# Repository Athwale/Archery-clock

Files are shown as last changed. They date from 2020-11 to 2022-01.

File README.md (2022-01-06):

# REV1 boards have not been built and tested yet.
If you intend to build it, please wait.

# Archery-clock
This repository contains electronic designs and software for a custom built sport archery clock used by www.patriotbrno.cz

## V2
V2 is the current design which uses a Raspberry pi 3 and is controlled over wi-fi using a smartphone or a computer.  
It is built to be more modular and easier to build or repair.

## PCBs
The DXF and Gerber files are exported from copper side and must be mirror flipped by the manufacturer to produce correct boards, KiCad does not have this functionality built in. Drill files are included, but should be checked and adjusted according to your needs.  
Check the position of pin 1 on the microcontroller (square pad in the design) for correct stencil placement.

## Control software  
The clock has a web based user interface that you can use from a wif-fi capable phone or computer.  
This software is being developed here:  
https://github.com/zmej/arclock

### Viewing the designs
Electronic designs were made in KiCad.

### Disclaimer
These designs were not professionally produced nor rigorously tested by any institution. You are building this device on your own and you accept all responsibility for it's function and operation.

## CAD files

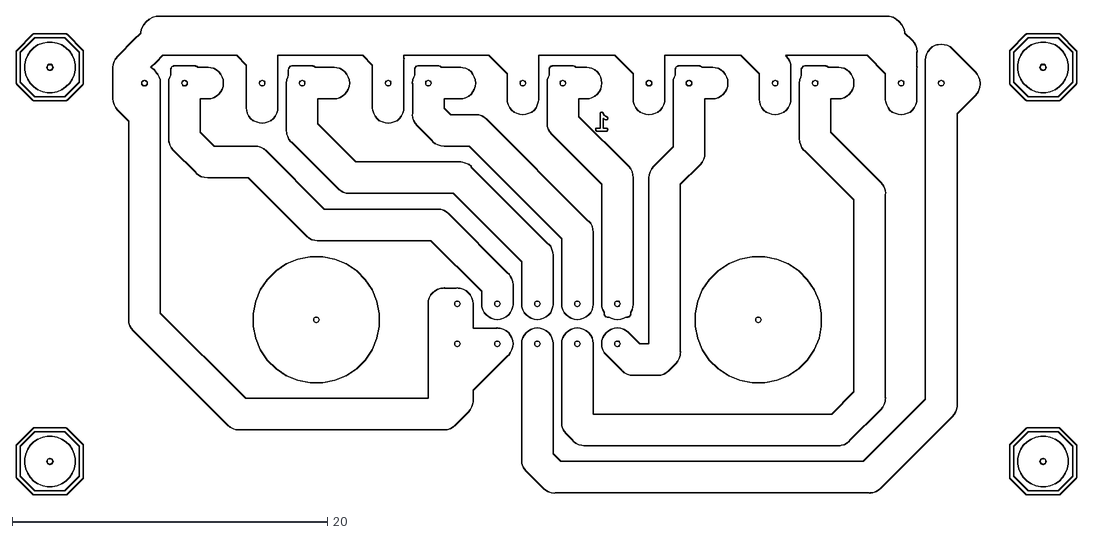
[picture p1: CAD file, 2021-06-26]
V2-rev1/Hardware/breakout/DXF/breakout-B_Cu.dxf
67.3 x 30.4

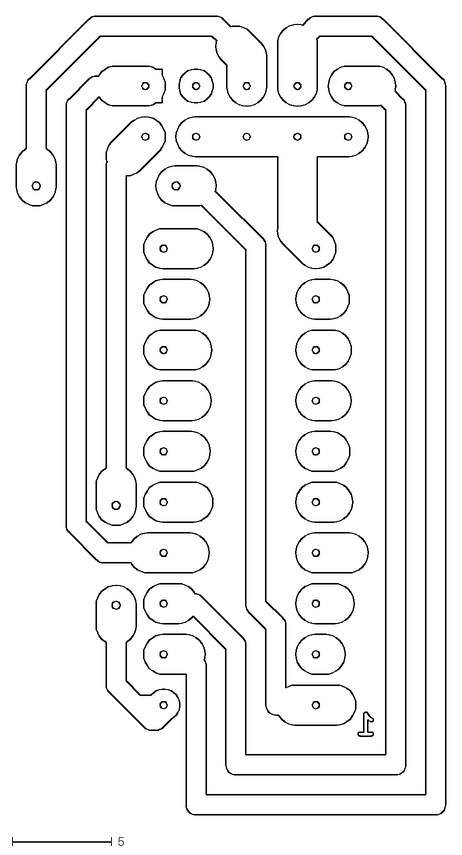
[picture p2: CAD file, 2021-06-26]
V2-rev1/Hardware/burner/DXF/burner-B_Cu.dxf
21.5 x 40.0

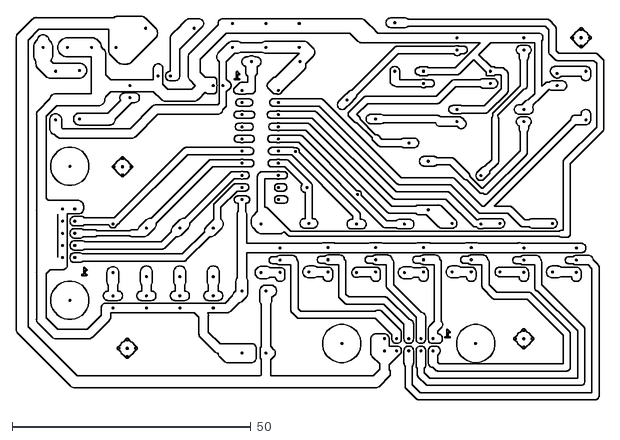
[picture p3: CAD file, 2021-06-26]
V2-rev1/Hardware/controller/DXF/controller-B_Cu.dxf
123.0 x 80.3

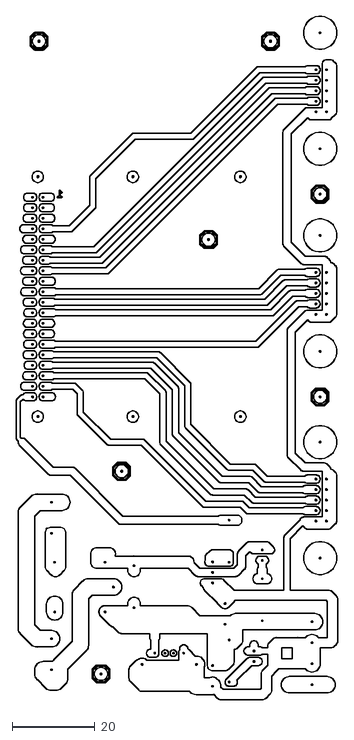
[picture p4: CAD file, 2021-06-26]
V2-rev1/Hardware/splitter/DXF/splitter-B_Cu.dxf
77.8 x 165.3

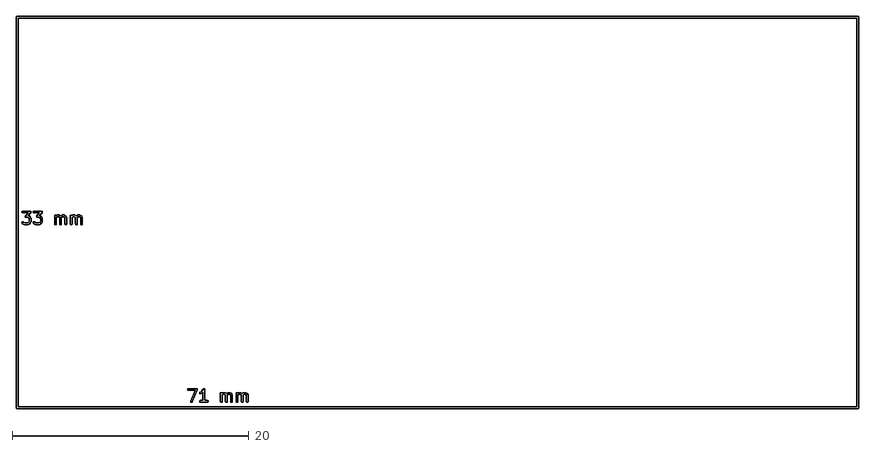
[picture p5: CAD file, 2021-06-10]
V2-rev1/Hardware/breakout/DXF/breakout-Eco2_User.dxf
71.1 x 33.2

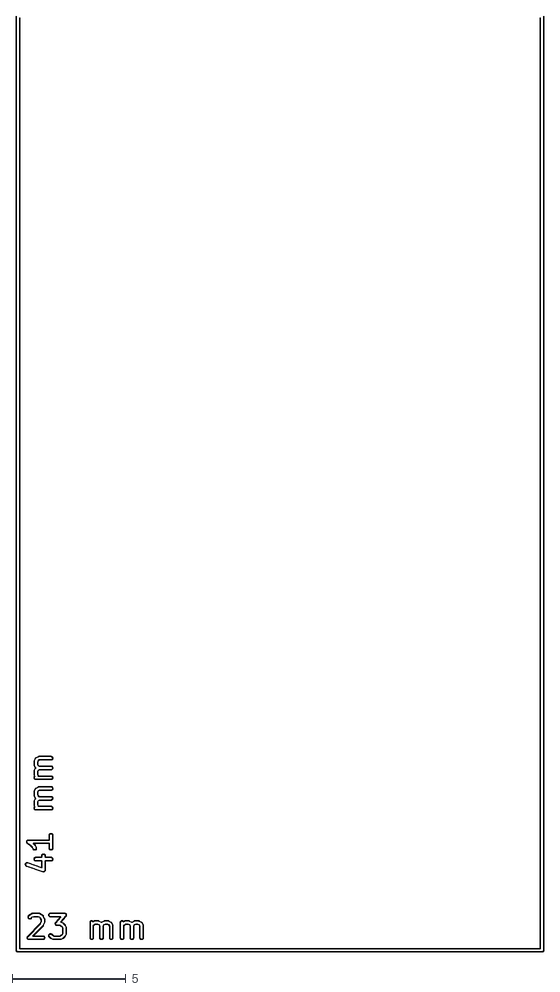
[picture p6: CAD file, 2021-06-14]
V2-rev1/Hardware/burner/DXF/burner-Eco2_User.dxf
23.1 x 41.1

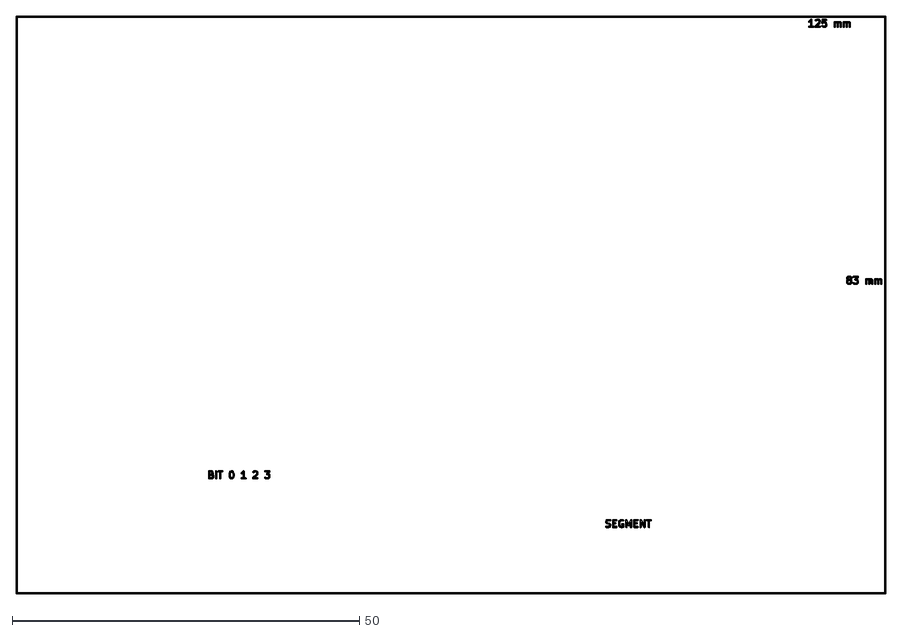
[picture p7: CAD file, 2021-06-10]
V2-rev1/Hardware/controller/DXF/controller-Eco2_User.dxf
125.2 x 83.2

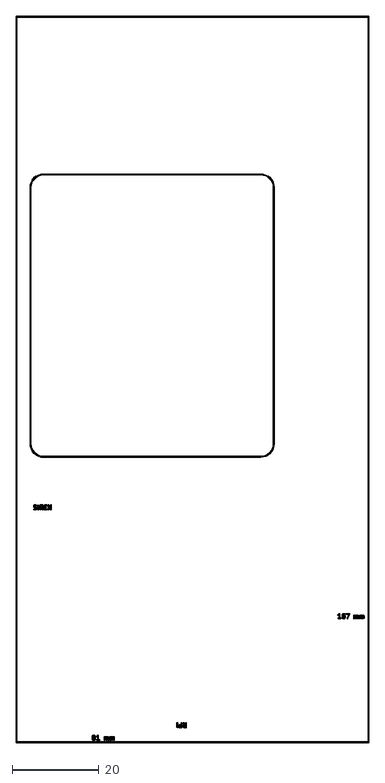
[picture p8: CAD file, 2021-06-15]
V2-rev1/Hardware/splitter/DXF/splitter-Eco2_User.dxf
81.2 x 167.2

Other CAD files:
V2-rev1/Hardware/breakout/DXF/breakout-B_Mask.dxf
V2-rev1/Hardware/burner/DXF/burner-B_Mask.dxf
V2-rev1/Hardware/controller/DXF/controller-B_Mask.dxf
V2-rev1/Hardware/splitter/DXF/splitter-B_Mask.dxf

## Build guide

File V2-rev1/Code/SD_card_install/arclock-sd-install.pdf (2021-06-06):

# ARCLOCK Image

Dokumentace je napsaná pro OS Linux. U nás nepoužíváme Windows, ale ve Windows budou určitě existovat ekvivalentní nástroje.

Stav. V hodinách byla SD karta 16GB a měli jsme rezervní kartu jen 8GB. Potřebovali jsme vyzkoušet, že stažený image bude po restore opět fungovat.
Když jsem stahoval image z SDD16GB pomoci dd a ten jsem opět pomocí dd nahrál na SDD8GB, tak hodiny nenaběhly.

Proto jsme použili utilitu image-backup. Ta neni v Raspbianu předinstalovaná a bylo potřeba ji doinstalovat.

image-backup jsme nainstalovali do adresáře /home/pi/utils

# Příprava záložního média

Image SDD karty je potřeba umístit na záložní médium, u mě to byl USB flash disk. Image vyžaduje zhruba 5GB, ale přidali jsme zhruba 2GB volného místa, aby byla rezerva na logy a pod.
Na USB flash disku jsem vytvořil dostatečně velký partition se souborovým systémem Ext4. Image má skoro 7GB a souborový systém musí zvládnout práci s tak velkým souborem.

# Vytvoření image

Do USB portu RPi zasunout připravené záložní médium.

Spustit image-backup. V našem případě by to vypadalo:

$ sudo ~/utils/image-backup

image-backup pracuje interaktivne a postupně se zeptá na následujćí otázky:
- Název souboru s image. Musí obsahovat cestu na záložní médium, a to i v případě, že na záložním médiu je aktuální pracovní adresář. V mém přṕadě to bylo: /media/pi/samsung32g/rpi-arclock.img .
- Kolik místa má alokovat pro root file systém. Zadal jsem 7168.
- Kolik místa má přidat pro pozdější inkrementální backup. Zadal jsem 0
- Nakonec je potvrzení, že se má image vytvorit - y .

Zkomprimovat soubor:
$ gzip -k /media/pi/samsung32g/rpi-arclock.img

Vznikne soubor /media/pi/samsung32g/rpi-arclock.img.gz

Diky přepínači -k zůstane zachován i původní soubor.

# Instalace SD karty z image

Do svého notebooku jsem zasunul záložní médium do USB konektoru a SD kartu do SD slotu.

Rozbalit image soubor z archivu gz.

Zatím jsem nevyzkoušel instalovat SD kartu příkazem dd, pracoval jsem s GUI utilitou disks.
- Vybrat v levém panelu SD kartu.
- V nástrojové liště kliknou na druhé tlačítko zprava. To se třemi linkami.
- V menu vybrat Restore disk image ...

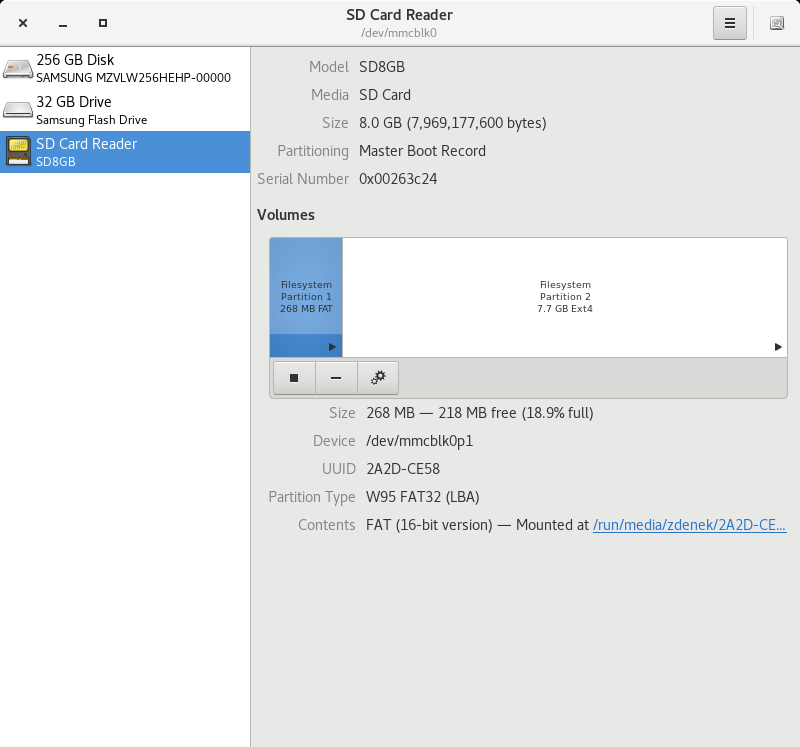
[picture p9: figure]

- Kliknout na tlačítko vedle nápisu Image to Restore a vybrat soubor.

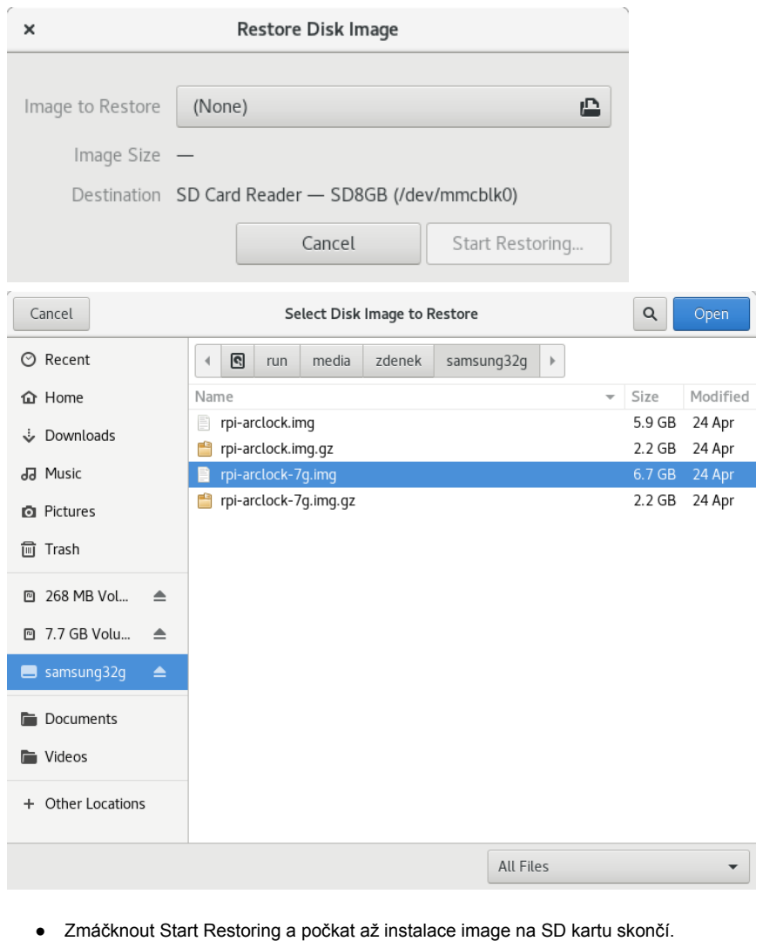
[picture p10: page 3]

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
ž in

s

t

ala

c

e im

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
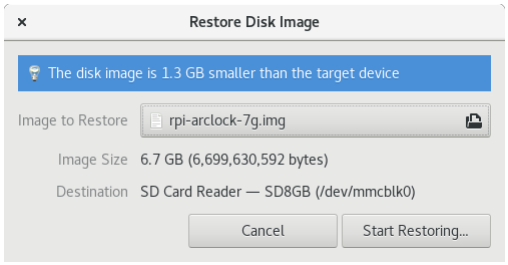
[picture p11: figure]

# Instalace SD karty do RPi

Zasunout SD kartu do slotu v RPi.

Zapnout hodiny.

Na RPI by měla celou dobu bootu blikat i zelená kontrolka. Pokud nebliká, je něco špatně.

Boot poměrně dlouho trvá, je potřeba vydržet.

Na konci bootu by se měly postupně na LEDkách kontrolérů, a je-li připojen displej, tak i na něm, rozsvítit a zhasnout číslice 8 a nakonec by na displeji měly svítit dvě pomlčky na místě jednotek a desítek.

Zapnout nějaké zařízení s Wifi, notebook, tablet, mobil.

V seznamu dostupných Wifi sítí by se měla objevit síť ArcheryClock

Připojit se k síti ArcheryClock. Heslo je whiteblinkingdot

Na zařízení spustit internetový prohlížeč. Testoval jsem s prohlížeči Firefox, Chrome. Zkusil jsem i se Safari, ale Sfari mělo problém, že vždy po dokončení odpočtu zapomělo nastavení a bylo potřeba znovu v UI nastavit řadu a délku odpočtu.

Do prohlížeče zadat adresu: 192.168.4.1:4000

Objeví se

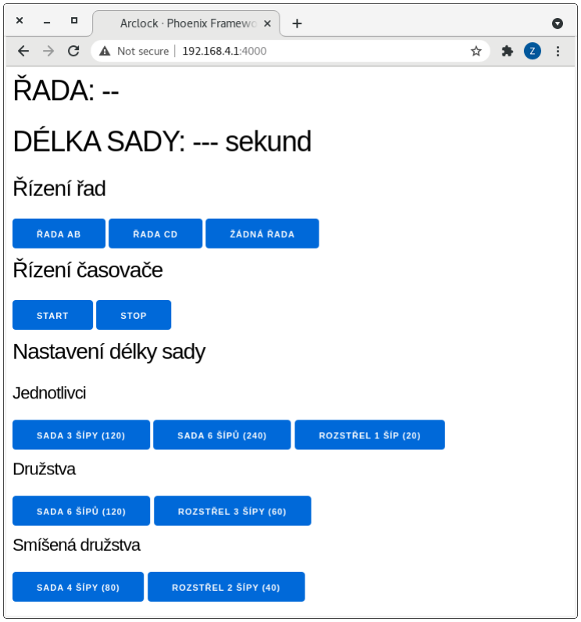
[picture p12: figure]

Zacházení s UI už nepotřebuje další komentář ;-) .

Hodiny nepotřebují žádnou speciální akci pro shutdown. Stačí vypnout přívod 230V.

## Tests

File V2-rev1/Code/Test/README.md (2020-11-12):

Microcontroller: AVR, EEPROM: 128B, SRAM: 128B, flash: 2kB, THT ATTINY2313-20PU DIL20  
Programmer: USBASP - USB 2.0 ISP programmer  
Burner SW: AVRDUDE  
OS: Fedora  
    
## Install:
```
sudo yum -y install avrdude avr-gcc avr-libc
```

### Simple LED test:
This compiles and creates a hex file for a small LED blinking test program which blinks all LEDs connected to port B at 500ms intervals using the default internal 1MHz rc oscillator.
```
avr-gcc -Wall -g -Os -mmcu=attiny2313 -o ledblink_test.bin ledblink_test.c  
avr-objcopy -j .text -j .data -O ihex ledblink_test.bin ledblink_test.hex  
```
  
#### Flash hex into the microcontroller:
```
avrdude -c usbasp -p attiny2313 -U flash:w:ledblink_test.hex
```

### Decoder IO test:
This test sends all possible displayable characters on port B using another attiny2313 using the internal 1MHz rc oscillator.
```
avr-gcc -Wall -g -Os -mmcu=attiny2313 -o io_test.bin io_test.c  
avr-objcopy -j .text -j .data -O ihex io_test.bin io_test.hex  
```
  
#### Flash hex into the microcontroller:
```
avrdude -c usbasp -p attiny2313 -U flash:w:io_test.hex
```

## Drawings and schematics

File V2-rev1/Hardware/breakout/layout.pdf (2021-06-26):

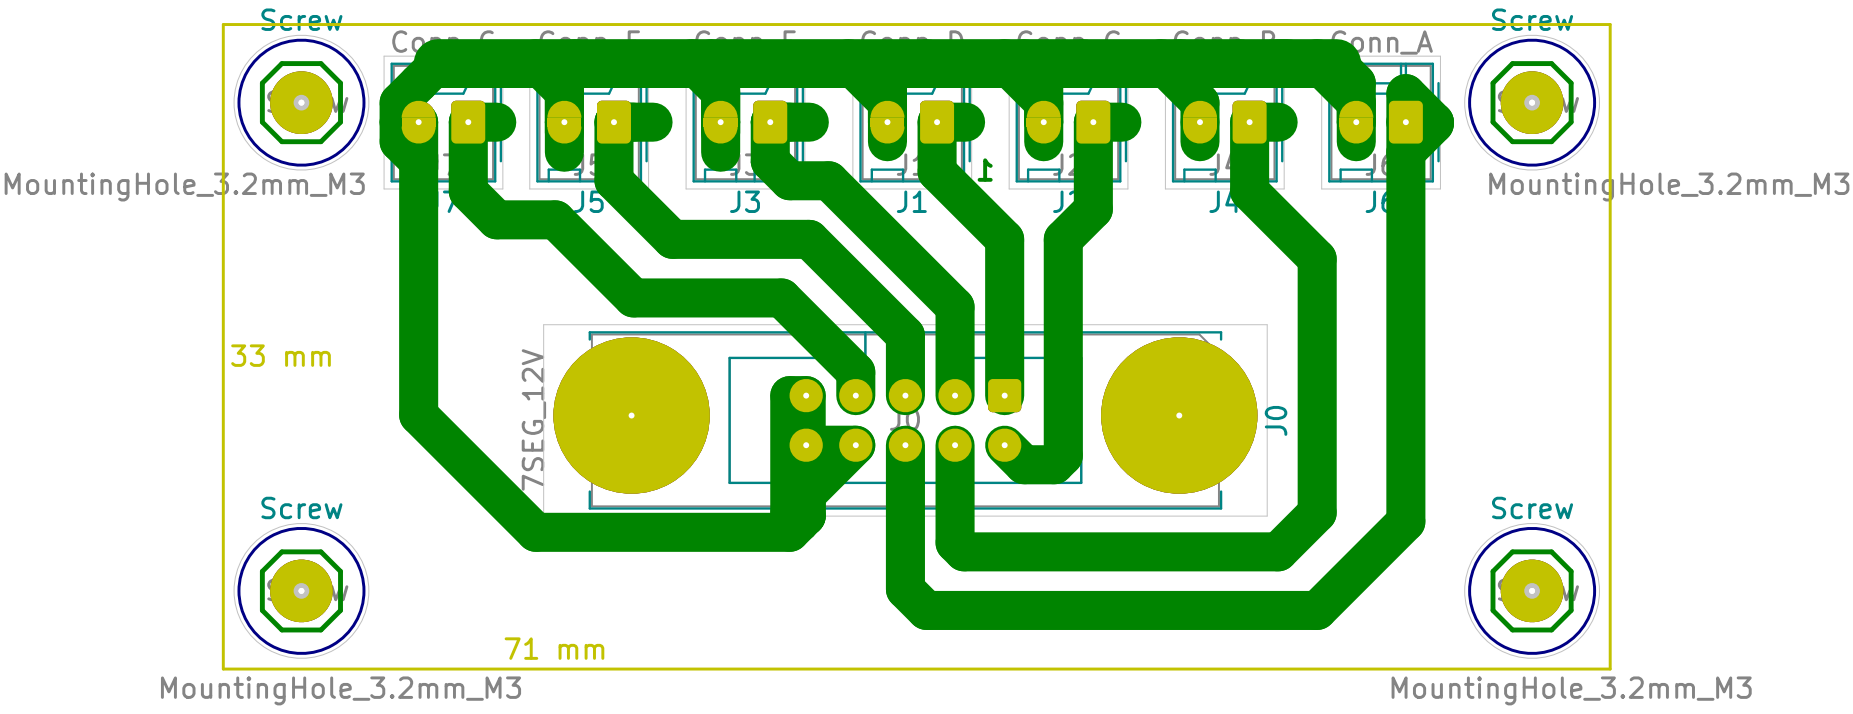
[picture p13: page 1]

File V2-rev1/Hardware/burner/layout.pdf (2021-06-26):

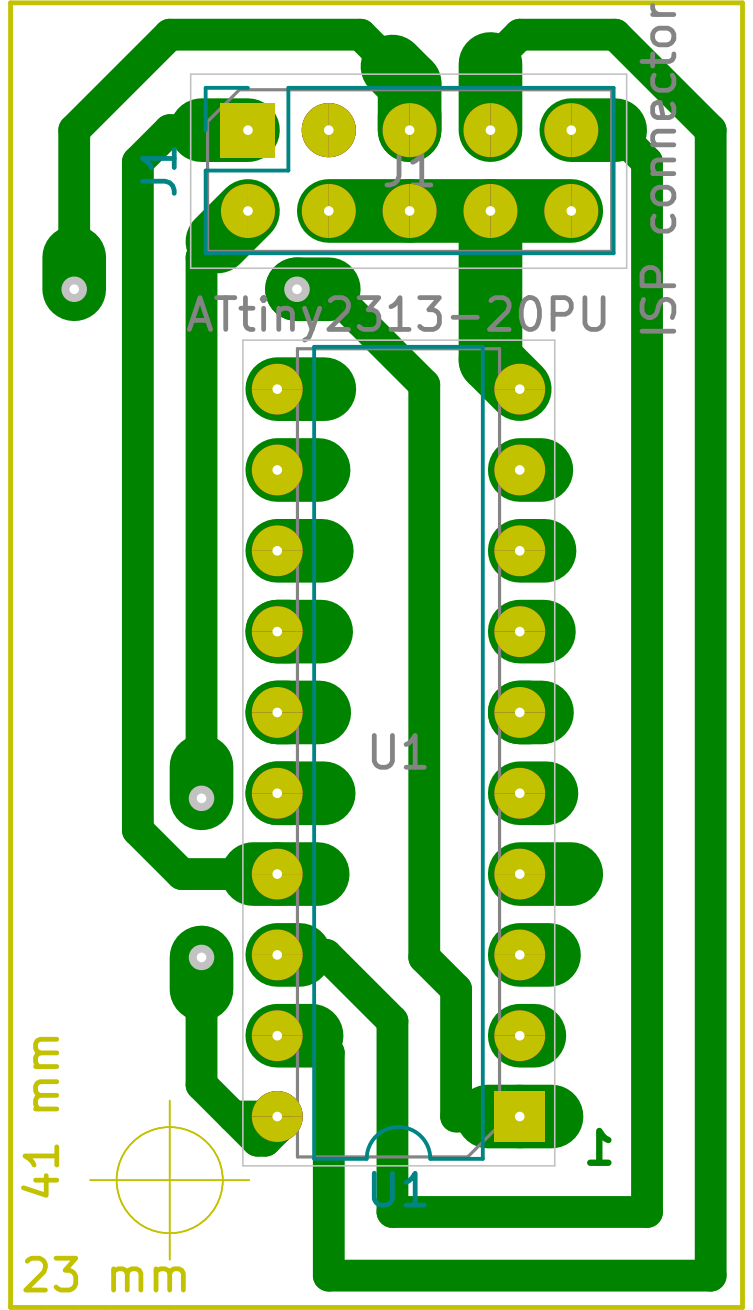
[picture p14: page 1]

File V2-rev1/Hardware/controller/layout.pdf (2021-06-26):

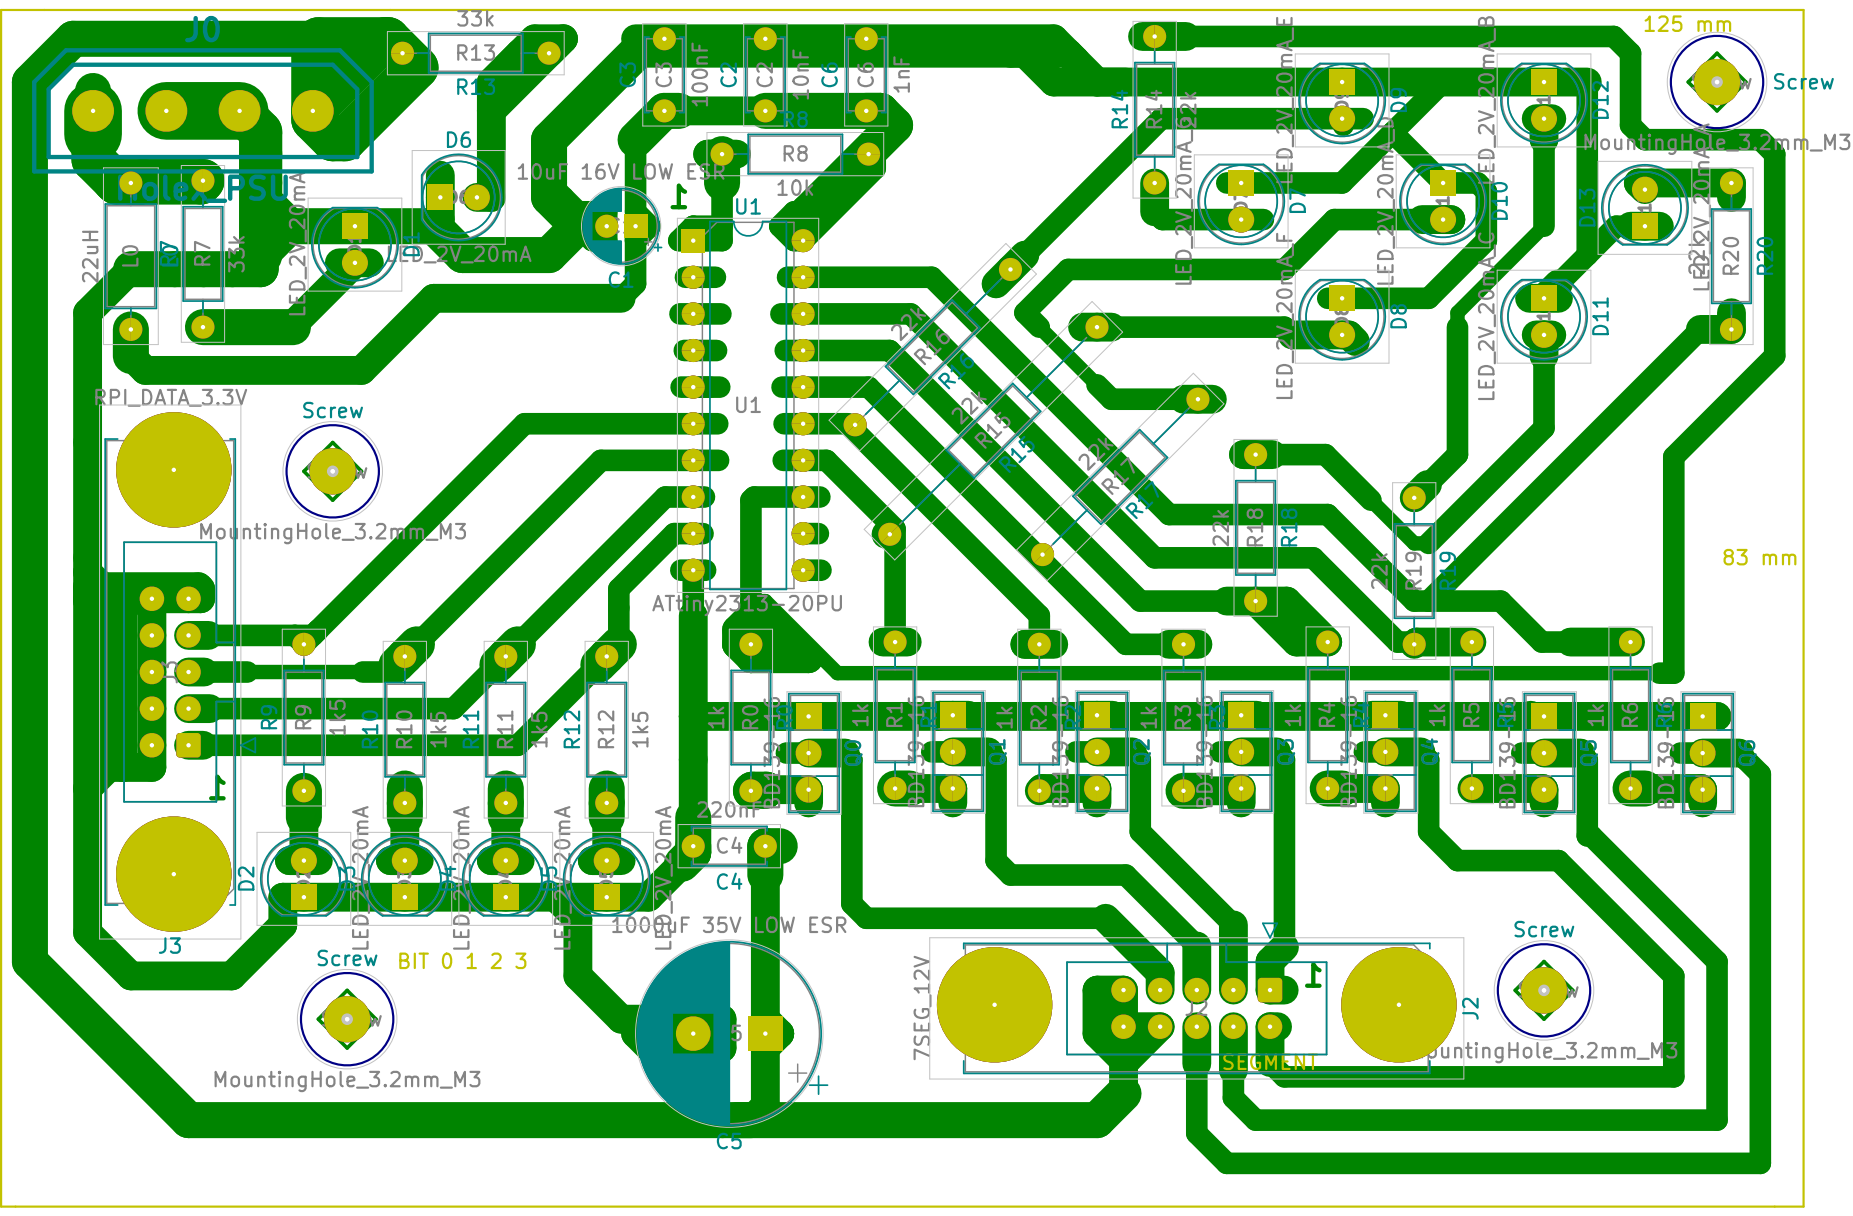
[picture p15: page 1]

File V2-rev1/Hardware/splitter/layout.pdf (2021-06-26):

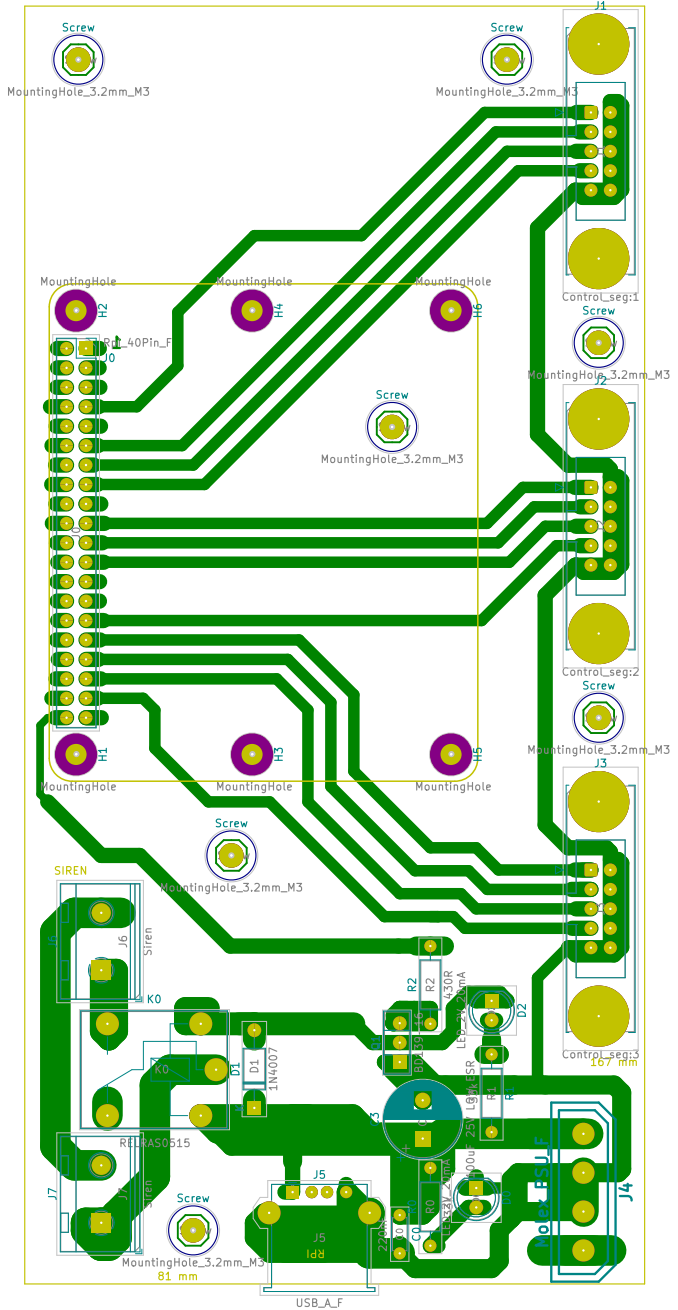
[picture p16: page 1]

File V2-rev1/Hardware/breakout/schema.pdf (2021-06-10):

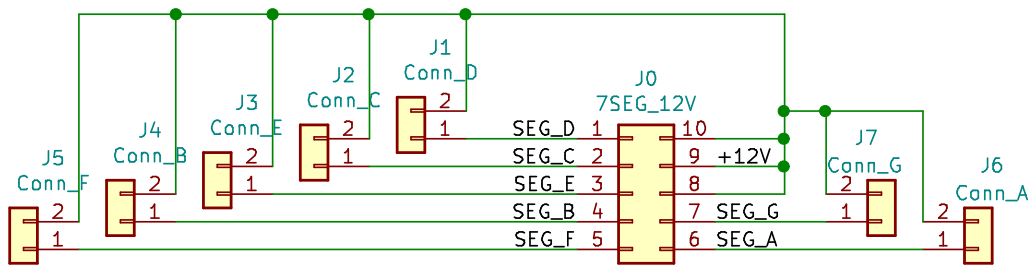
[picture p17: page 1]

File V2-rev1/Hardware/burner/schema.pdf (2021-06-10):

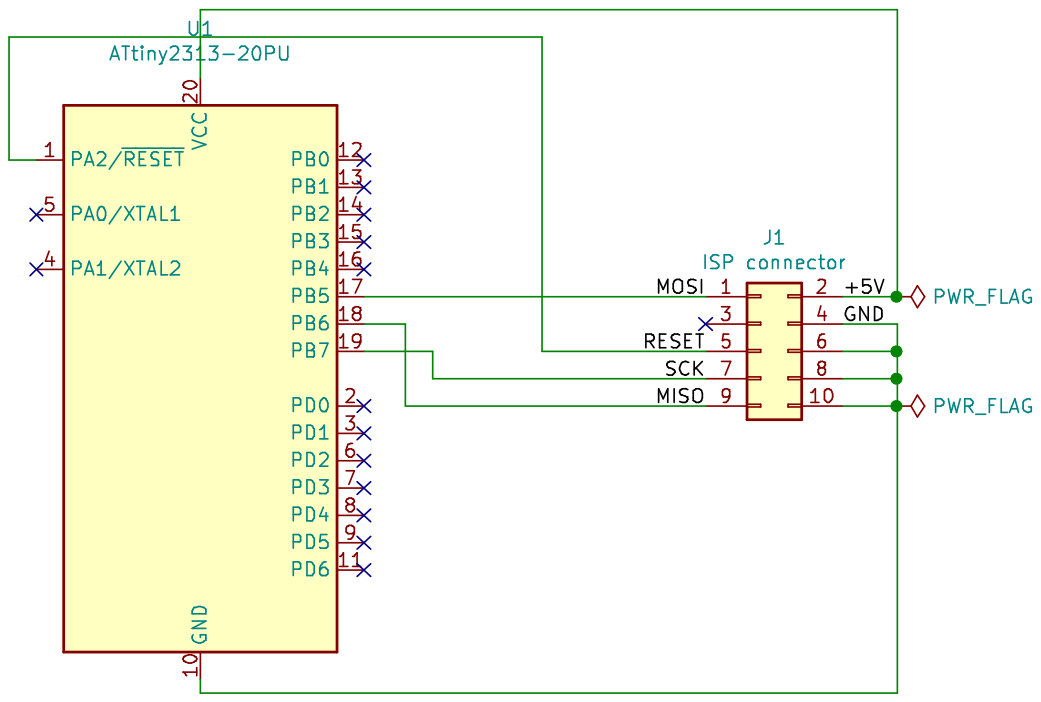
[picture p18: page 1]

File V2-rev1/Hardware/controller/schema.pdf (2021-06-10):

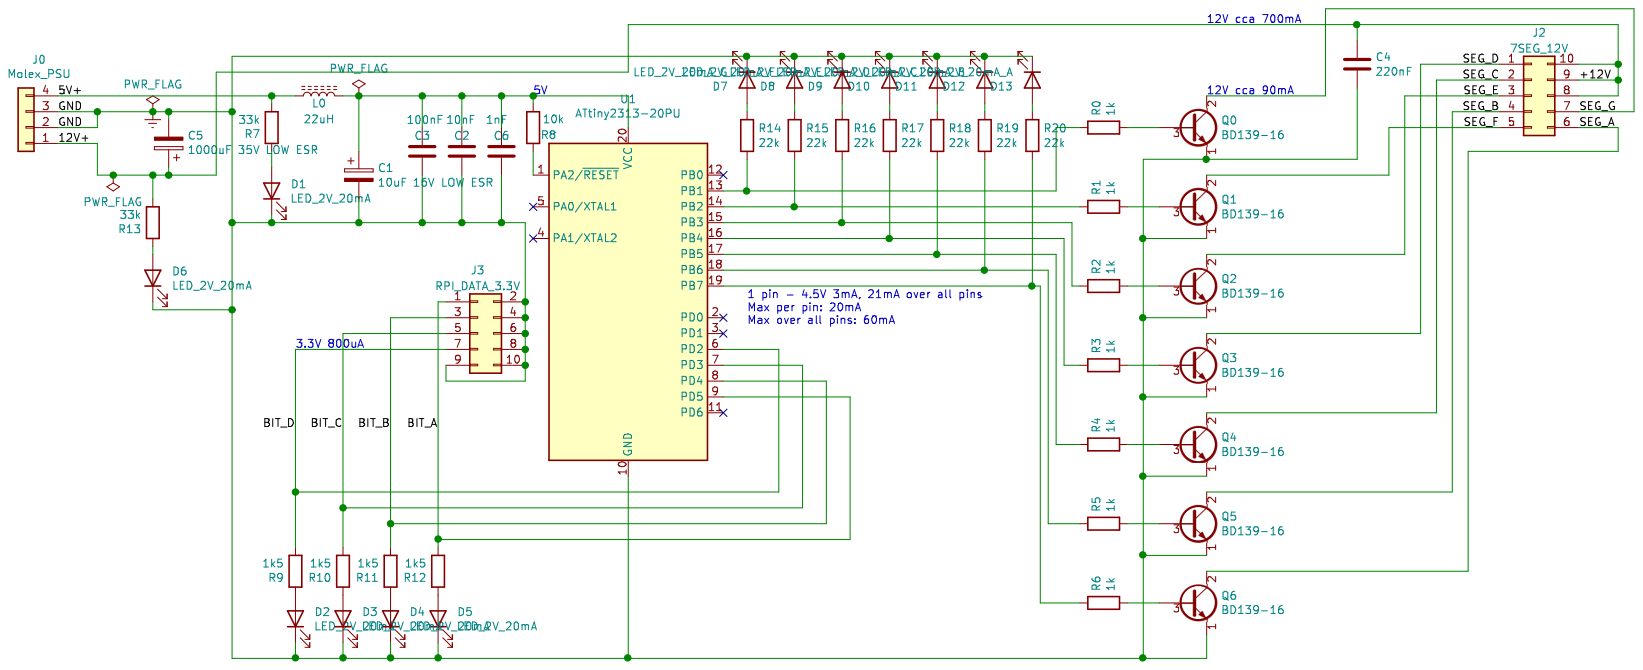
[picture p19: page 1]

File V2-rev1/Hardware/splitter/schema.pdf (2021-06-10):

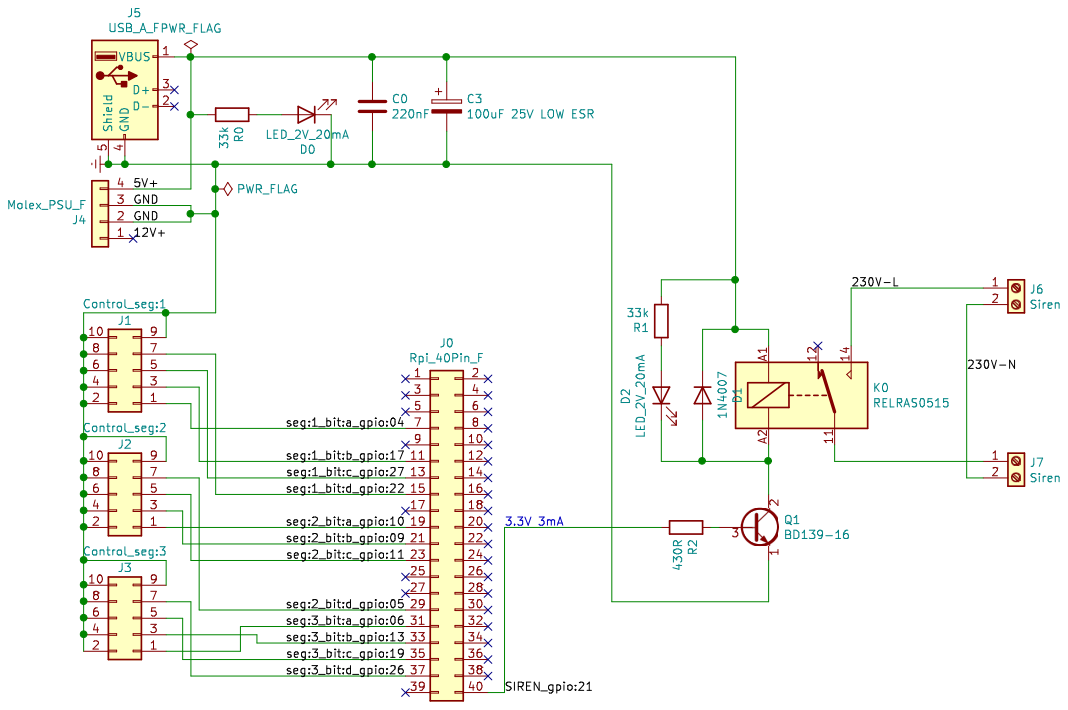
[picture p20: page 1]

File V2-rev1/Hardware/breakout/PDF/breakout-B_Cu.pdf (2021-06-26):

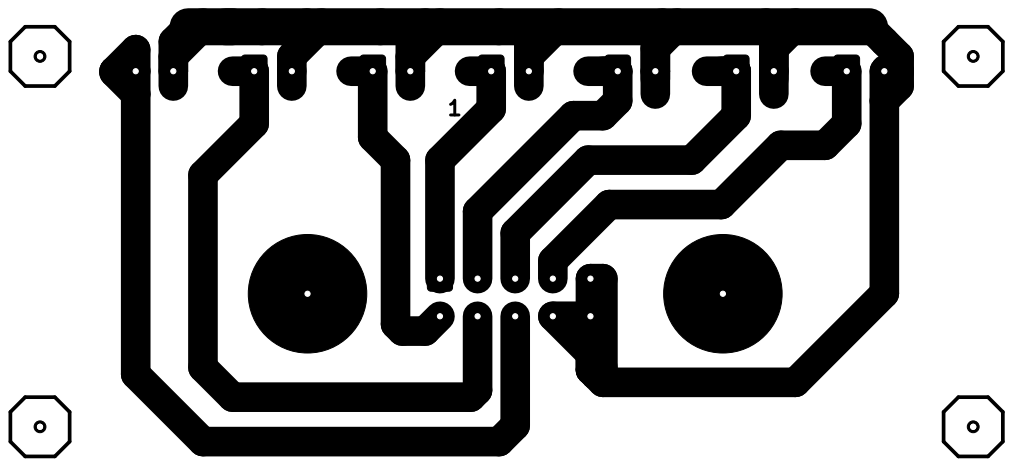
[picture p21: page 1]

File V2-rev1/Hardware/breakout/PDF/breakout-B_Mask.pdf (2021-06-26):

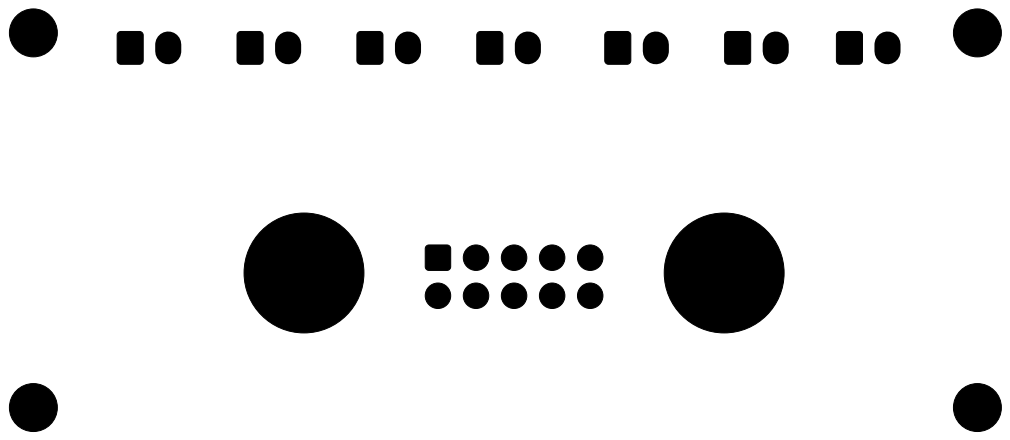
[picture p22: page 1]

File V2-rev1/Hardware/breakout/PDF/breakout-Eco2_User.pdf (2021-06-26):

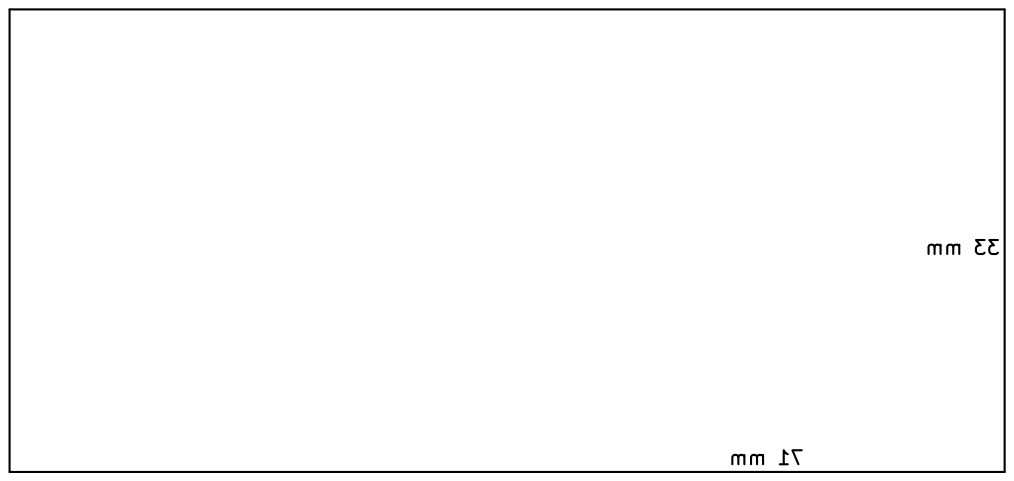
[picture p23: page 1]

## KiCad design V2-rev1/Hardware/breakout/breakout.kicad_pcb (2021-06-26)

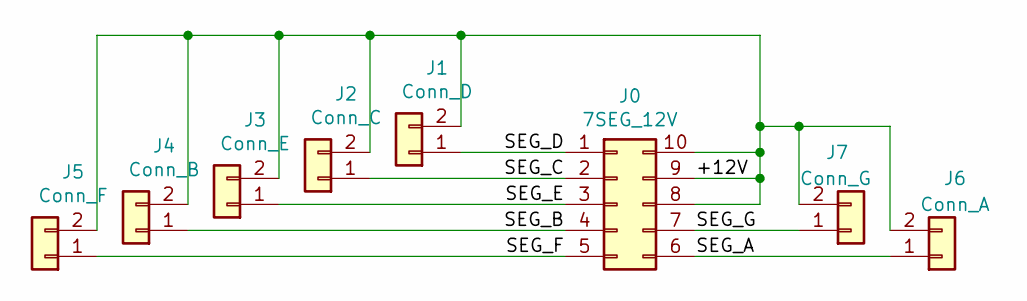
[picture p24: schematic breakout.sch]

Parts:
J0: 7SEG_12V; IDC-Header_2x05-1MP_P2.54mm_Latch_Vertical
J1: Conn_D; Molex_KK-254_AE-6410-02A_1x02_P2.54mm_Vertical
J2: Conn_C; Molex_KK-254_AE-6410-02A_1x02_P2.54mm_Vertical
J3: Conn_E; Molex_KK-254_AE-6410-02A_1x02_P2.54mm_Vertical
J4: Conn_B; Molex_KK-254_AE-6410-02A_1x02_P2.54mm_Vertical
J5: Conn_F; Molex_KK-254_AE-6410-02A_1x02_P2.54mm_Vertical
J6: Conn_A; Molex_KK-254_AE-6410-02A_1x02_P2.54mm_Vertical
J7: Conn_G; Molex_KK-254_AE-6410-02A_1x02_P2.54mm_Vertical

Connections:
/+12V: J0.8, J0.9, J0.10, J1.2, J2.2, J3.2, J4.2, J5.2, J6.2, J7.2
/SEG_A: J0.6, J6.1
/SEG_B: J0.4, J4.1
/SEG_C: J0.2, J2.1
/SEG_D: J0.1, J1.1
/SEG_E: J0.3, J3.1
/SEG_F: J0.5, J5.1
/SEG_G: J0.7, J7.1

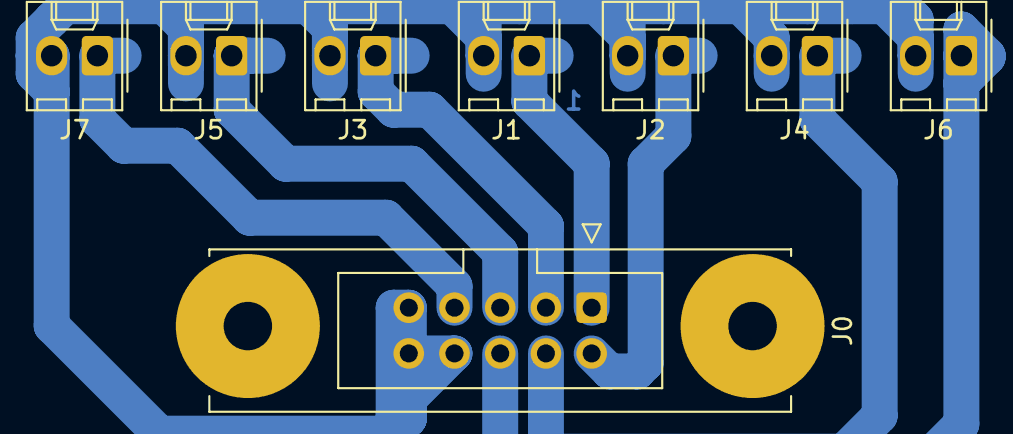
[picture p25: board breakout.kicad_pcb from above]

Board: 2 copper layers, 12 parts (0 on the bottom side), 8 nets.

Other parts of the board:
Screw: MountingHole_3.2mm_M3
Screw#2, Screw#3, Screw#4: MountingHole_3.2mm_M3

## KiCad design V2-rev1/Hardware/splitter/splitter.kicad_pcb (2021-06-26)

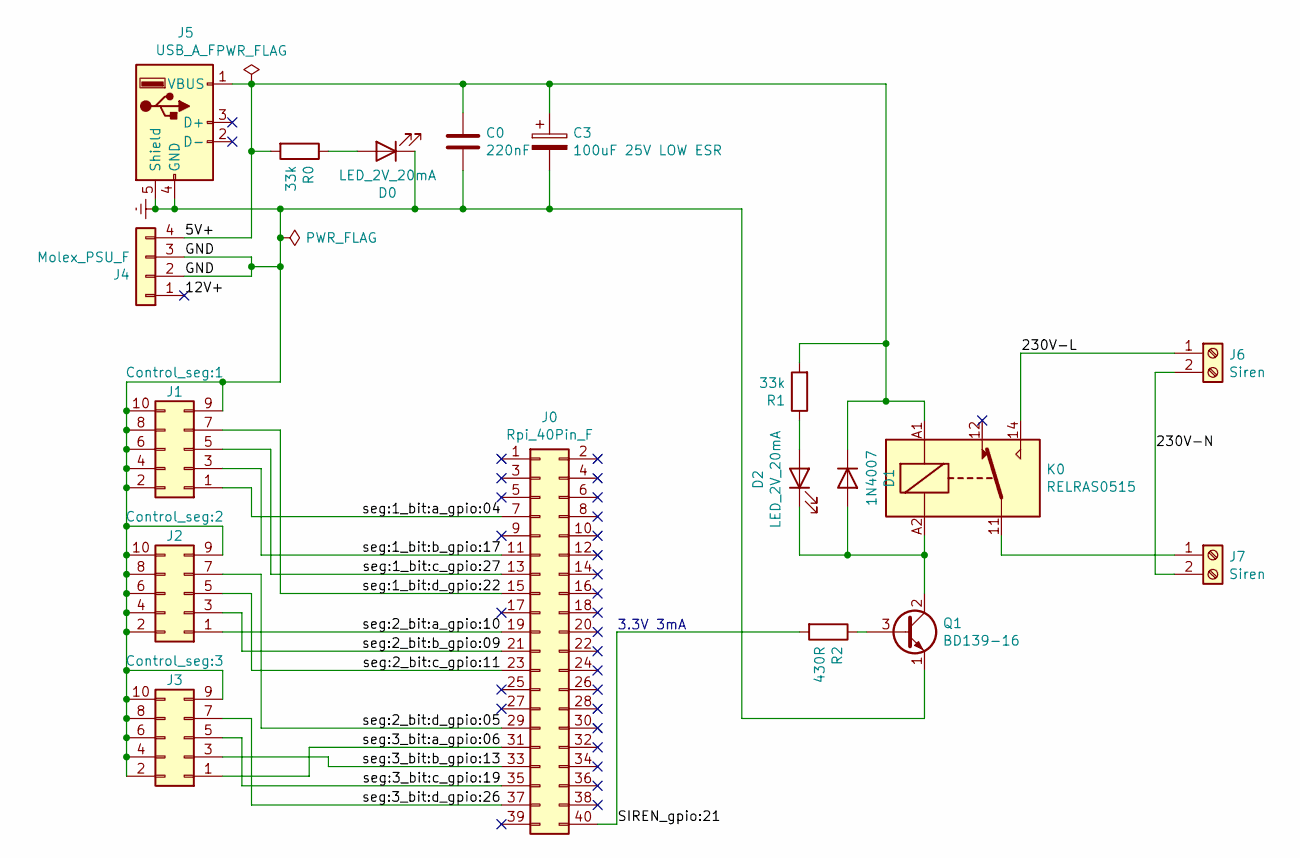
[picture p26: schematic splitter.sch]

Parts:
C0: 220nF; C_Disc_D4.3mm_W1.9mm_P5.00mm
C3: 100uF 25V LOW ESR; CP_Radial_D10.0mm_P5.00mm
D0, D2: LED_2V_20mA; LED_D5.0mm
D1: 1N4007; D_A-405_P10.16mm_Horizontal
J0: Rpi_40Pin_F; PinSocket_2x20_P2.54mm_Vertical
J1: Control_seg:1; IDC-Header_2x05-1MP_P2.54mm_Latch_Vertical
J2: Control_seg:2; IDC-Header_2x05-1MP_P2.54mm_Latch_Vertical
J3: Control_seg:3; IDC-Header_2x05-1MP_P2.54mm_Latch_Vertical
J4: Molex_PSU_F; conn_hdd_15-24-4449
J5: USB_A_F; USB_A_Stewart_SS-52100-001_Horizontal
J6, J7: Siren; TerminalBlock_RND_205-00067_1x02_P7.50mm_Horizontal
K0: RELRAS0515; Relay_SPDT_Finder_36.11
Q1: BD139-16; TO-126-3_Vertical
R0, R1: 33k; R_Axial_DIN0207_L6.3mm_D2.5mm_P10.16mm_Horizontal
R2: 430R; R_Axial_DIN0207_L6.3mm_D2.5mm_P10.16mm_Horizontal

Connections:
/5V+: C0.1, C3.1, D1.1 (K), J4.4, J5.1 (VBUS), K0.A1, R0.2, R1.2
/12V+: J4.1
/230V-L: J6.1, K0.14
/230V-N: J6.2, J7.2
/SIREN_gpio:21: J0.40, R2.2
/seg:1_bit:a_gpio:04: J0.7, J1.1
/seg:1_bit:b_gpio:17: J0.11, J1.3
/seg:1_bit:c_gpio:27: J0.13, J1.5
/seg:1_bit:d_gpio:22: J0.15, J1.7
/seg:2_bit:a_gpio:10: J0.19, J2.1
/seg:2_bit:b_gpio:09: J0.21, J2.3
/seg:2_bit:c_gpio:11: J0.23, J2.5
/seg:2_bit:d_gpio:05: J0.29, J2.7
/seg:3_bit:a_gpio:06: J0.31, J3.1
/seg:3_bit:b_gpio:13: J0.33, J3.3
/seg:3_bit:c_gpio:19: J0.35, J3.5
/seg:3_bit:d_gpio:26: J0.37, J3.7
Earth: C0.2, C3.2, D0.1 (K), J1.2, J1.4, J1.6, J1.8, J1.9, J1.10, J2.2, J2.4, J2.6, J2.8, J2.9, J2.10, J3.2, J3.4, J3.6, J3.8, J3.9, J3.10, J4.2, J4.3, J5.4 (GND), J5.5 (Shield), Q1.1 (E)
unnamed: D0.2 (A), R0.1
unnamed: D1.2 (A), D2.1 (K), K0.A2, Q1.2 (C)
unnamed: D2.2 (A), R1.1
unnamed: J7.1, K0.11
unnamed: Q1.3 (B), R2.1

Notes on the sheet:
3.3V 3mA

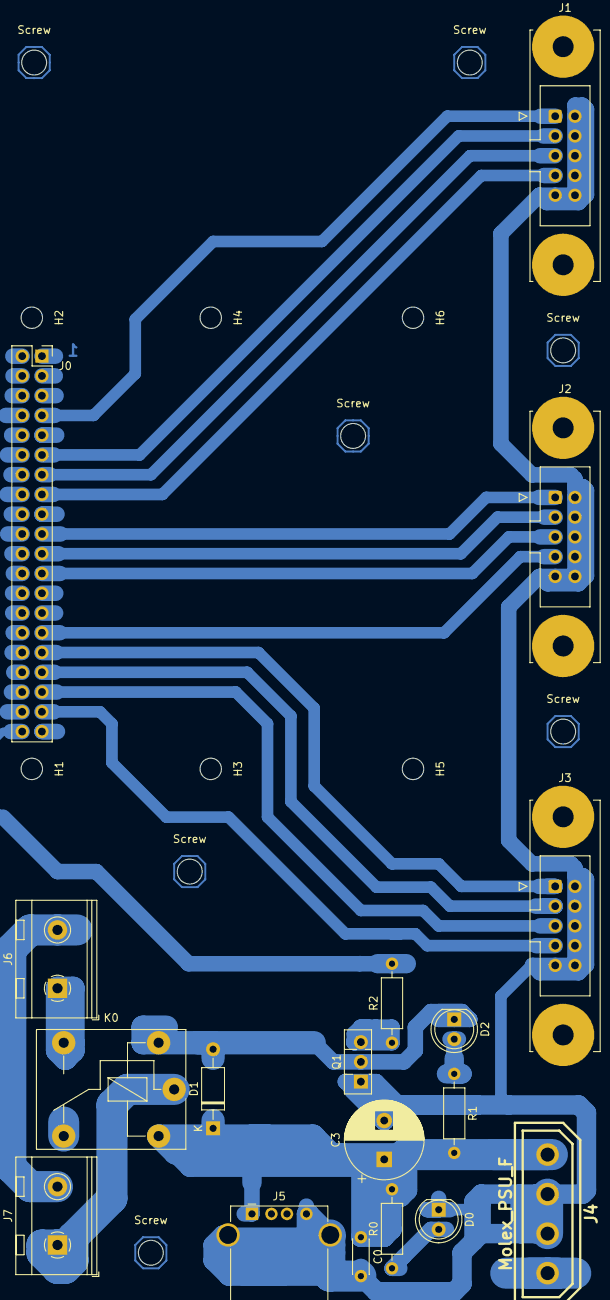
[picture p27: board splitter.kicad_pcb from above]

Board: 2 copper layers, 31 parts (0 on the bottom side), 22 nets.

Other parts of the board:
H1, H2, H3, H4, H5, H6: MountingHole; MountingHole_2.75mm_NoPad
Screw: MountingHole_3.2mm_M3
Screw#2, Screw#3, Screw#4, Screw#5, Screw#6, Screw#7: MountingHole_3.2mm_M3

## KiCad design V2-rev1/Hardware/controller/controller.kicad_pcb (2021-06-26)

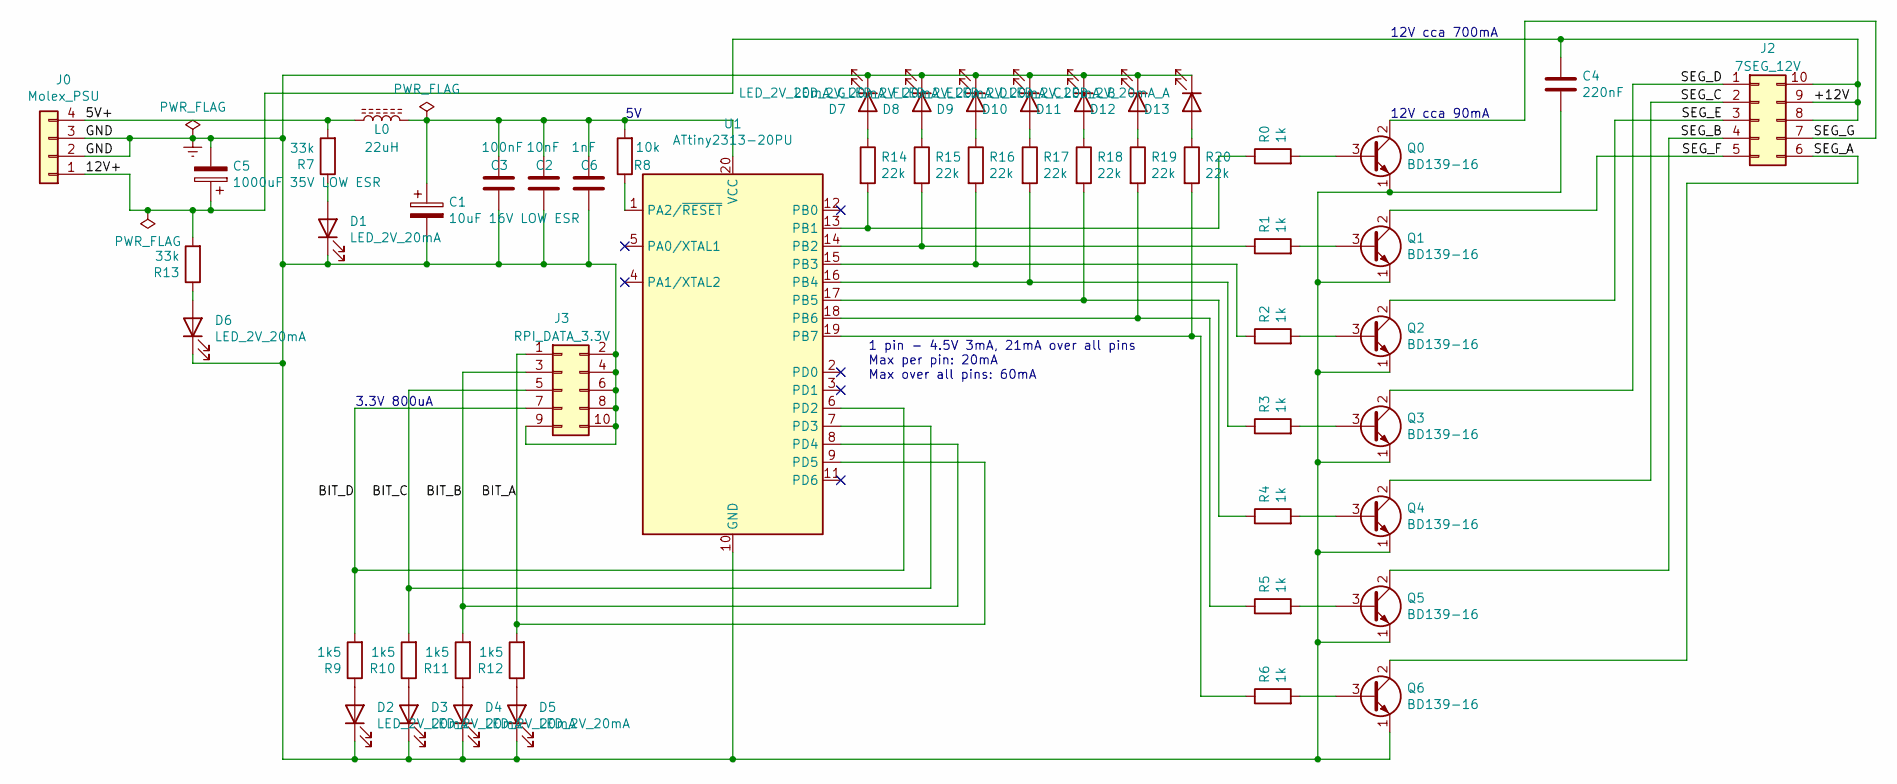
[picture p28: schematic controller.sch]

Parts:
C1: 10uF 16V LOW ESR; CP_Radial_D5.0mm_P2.00mm
C2: 10nF; C_Disc_D5.0mm_W2.5mm_P5.00mm
C3: 100nF; C_Disc_D5.0mm_W2.5mm_P5.00mm
C4: 220nF; C_Disc_D5.0mm_W2.5mm_P5.00mm
C5: 1000uF 35V LOW ESR; CP_Radial_D12.5mm_P5.00mm
C6: 1nF; C_Disc_D5.0mm_W2.5mm_P5.00mm
D1, D2, D3, D4, D5, D6: LED_2V_20mA; LED_D5.0mm
D7: LED_2V_20mA_G; LED_D5.0mm
D8: LED_2V_20mA_F; LED_D5.0mm
D9: LED_2V_20mA_E; LED_D5.0mm
D10: LED_2V_20mA_D; LED_D5.0mm
D11: LED_2V_20mA_C; LED_D5.0mm
D12: LED_2V_20mA_B; LED_D5.0mm
D13: LED_2V_20mA_A; LED_D5.0mm
J0: Molex_PSU; conn_hdd_15-24-4449
J2: 7SEG_12V; IDC-Header_2x05-1MP_P2.54mm_Latch_Vertical
J3: RPI_DATA_3.3V; IDC-Header_2x05-1MP_P2.54mm_Latch_Vertical
L0: 22uH; L_Axial_L7.0mm_D3.3mm_P10.16mm_Horizontal_Fastron_MICC
Q0, Q1, Q2, Q3, Q4, Q5, Q6: BD139-16; TO-126-3_Vertical
R0, R1, R2, R3, R4, R5, R6: 1k; R_Axial_DIN0207_L6.3mm_D2.5mm_P10.16mm_Horizontal
R7, R13: 33k; R_Axial_DIN0207_L6.3mm_D2.5mm_P10.16mm_Horizontal
R8: 10k; R_Axial_DIN0207_L6.3mm_D2.5mm_P10.16mm_Horizontal
R9, R10, R11, R12: 1k5; R_Axial_DIN0207_L6.3mm_D2.5mm_P10.16mm_Horizontal
R14, R18, R19, R20: 22k; R_Axial_DIN0207_L6.3mm_D2.5mm_P10.16mm_Horizontal
R15, R16, R17: 22k; R_Axial_DIN0207_L6.3mm_D2.5mm_P15.24mm_Horizontal
U1: ATtiny2313-20PU; DIP-20_W7.62mm

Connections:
/5V+: J0.4, L0.1, R7.2
/+12V: C4.1, C5.1, J0.1, J2.8, J2.9, J2.10, R13.2
/BIT_A: J3.1, R12.2, U1.9 (PD5)
/BIT_B: J3.3, R11.2, U1.8 (PD4)
/BIT_C: J3.5, R10.2, U1.7 (PD3)
/BIT_D: J3.7, R9.2, U1.6 (PD2)
/SEG_A: J2.6, Q6.2 (C)
/SEG_B: J2.4, Q5.2 (C)
/SEG_C: J2.2, Q4.2 (C)
/SEG_D: J2.1, Q3.2 (C)
/SEG_E: J2.3, Q2.2 (C)
/SEG_F: J2.5, Q1.2 (C)
/SEG_G: J2.7, Q0.2 (C)
Earth: C1.2, C2.2, C3.2, C4.2, C5.2, C6.2, D1.1 (K), D2.1 (K), D3.1 (K), D4.1 (K), D5.1 (K), D6.1 (K), D7.1 (K), D8.1 (K), D9.1 (K), D10.1 (K), D11.1 (K), D12.1 (K), D13.1 (K), J0.2, J0.3, J3.2, J3.4, J3.6, J3.8, J3.9, J3.10, Q0.1 (E), Q1.1 (E), Q2.1 (E), Q3.1 (E), Q4.1 (E), Q5.1 (E), Q6.1 (E), U1.10 (GND)
unnamed: C1.1, C2.1, C3.1, C6.1, L0.2, R8.2, U1.20 (VCC)
unnamed: D1.2 (A), R7.1
unnamed: D2.2 (A), R9.1
unnamed: D3.2 (A), R10.1
unnamed: D4.2 (A), R11.1
unnamed: D5.2 (A), R12.1
unnamed: D6.2 (A), R13.1
unnamed: D7.2 (A), R14.1
unnamed: D8.2 (A), R15.1
unnamed: D9.2 (A), R16.1
unnamed: D10.2 (A), R17.1
unnamed: D11.2 (A), R18.1
unnamed: D12.2 (A), R19.1
unnamed: D13.2 (A), R20.1
unnamed: Q0.3 (B), R0.2
unnamed: Q1.3 (B), R1.2
unnamed: Q2.3 (B), R2.2
unnamed: Q3.3 (B), R3.2
unnamed: Q4.3 (B), R4.2
unnamed: Q5.3 (B), R5.2
unnamed: Q6.3 (B), R6.2
unnamed: R0.1, R14.2, U1.13 (PB1)
unnamed: R1.1, R15.2, U1.14 (PB2)
unnamed: R8.1, U1.1 (PA2/~RESET)
unnamed: R2.1, R16.2, U1.15 (PB3)
unnamed: R3.1, R17.2, U1.16 (PB4)
unnamed: R4.1, R18.2, U1.17 (PB5)
unnamed: R5.1, R19.2, U1.18 (PB6)
unnamed: R6.1, R20.2, U1.19 (PB7)

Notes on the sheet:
12V cca 90mA
12V cca 700mA
1 pin - 4.5V 3mA, 21mA over all pins Max per pin: 20mA Max over all pins: 60mA
3.3V 800uA

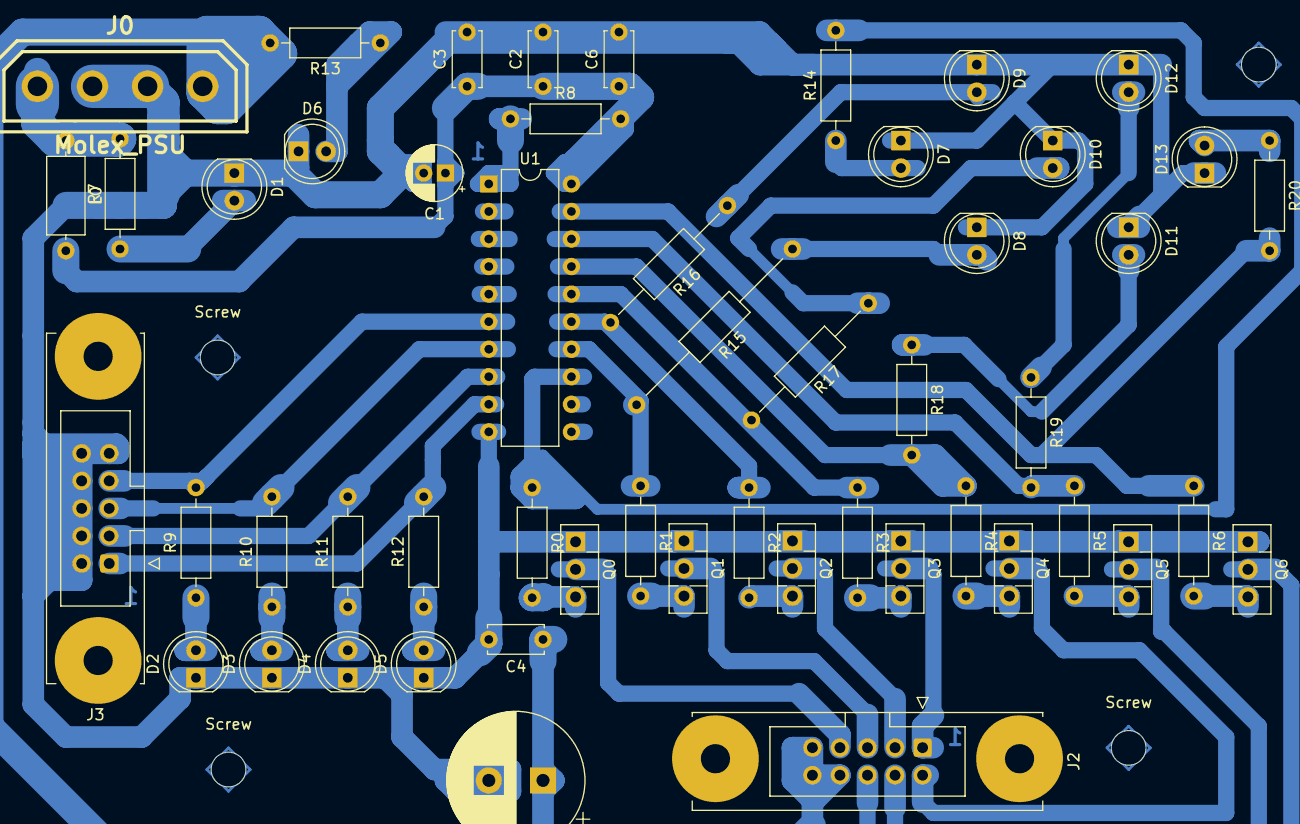
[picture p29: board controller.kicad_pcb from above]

Board: 2 copper layers, 56 parts (0 on the bottom side), 43 nets.

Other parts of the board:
Screw: MountingHole_3.2mm_M3
Screw#2, Screw#3, Screw#4: MountingHole_3.2mm_M3

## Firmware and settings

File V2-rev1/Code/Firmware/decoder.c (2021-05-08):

// This code decodes a 4 bit binary number into a 7 segment number or character a,b,c,d,-
// Chip: AVR, EEPROM: 128B, SRAM: 128B, flash: 2kB, THT ATTINY2313-20PU DIL20

// Pin configuration
// Outputs port B:
// DDRB = 0b | 1  | 1  | 1  | 1  | 1  | 1  | 1  | 1
// Segment:  | A  | B  | C  | D  | E  | F  | G  | Unused
// Pin num:  | 19 | 18 | 17 | 16 | 15 | 14 | 13 | 12
// Port num: | P7 | P6 | P5 | P4 | P3 | P2 | P1 | P0

// Input port D:
// Internal pull-up resistors disabled, external pull down 1.5k resistors are required 2mA per pin is drawn.
// Pin num:  | 6  | 7  | 8  | 9
// Port num: | 2  | 3  | 4  | 5
// Bit order:| 0  | 1  | 2  | 3

// Custom 7 segment display layout.
//      A
//     B C
//      D
//     E F
//      G

// Base frequency of the built in clock 1MHz.
#undef F_CPU
#define F_CPU 1000000UL

#include <util/delay.h>
#include <avr/io.h>

int decode[16] = {
    //ABCDEFG-
    0b11101110, // 0  
    0b00100100, // 1
    0b10111010, // 2
    0b10110110, // 3
    0b01110100, // 4
    0b11010110, // 5
    0b11011110, // 6
    0b10100100, // 7
    0b11111110, // 8
    0b11110110, // 9
    0b11111100, // a
    0b01011110, // b
    0b11001010, // c
    0b00111110, // d
    0b00010000, // -
    0b00000000, // Blank
};

void setup(void) {
    // Set all pins of port B to outputs.
    DDRB = 0b11111111;
    // Set pins 6,7,8,9 of port D as inputs 8th bit is not used.
    DDRD = 0b11000011;
    // Disable internal pull up resistors.
    PORTD = 0b00000000;
    
    // Signal setup OK, light up middle segment.
    PORTB = 0b00010000;
    _delay_ms(100);
    PORTB = 0b00000000;
    return;
}

int get_input_num(void) {
    // We are reading from PD2,3,4, PD0,1 will always be 0.
    // The binary number must shift right by 2 to produce the correct value.
    int input = PIND;
    input = input >> 2;
    return input;
}


void self_test(void) {
    // Light up all segments for a short while.
    PORTB = 0b11111111;
    _delay_ms(500);
    PORTB = 0b00000000;
    return;
}

void boot_animation(void) {
    // Show a boot animation on the display until number 8 is sent to the input.
    do {
        PORTB = 0b00000010;
        _delay_ms(250);
        PORTB = 0b00010000;
        _delay_ms(250);
        PORTB = 0b10000000;
        _delay_ms(250);
    } while(get_input_num() != 8);
    return;
}

void main_loop(void) {
    int input1;
    int input2;
    while(1) {
        // Filter out input interference by readig the same input twice after 50 ms and comparing it.
        input1 = get_input_num();
        _delay_ms(50);
        input2 = get_input_num();
        if(input1 == input2) {
            PORTB = decode[input2];
        }
    }
    return;
}

int main(void) {
    setup();
    self_test();
    boot_animation();
    main_loop();
    return 0;
}

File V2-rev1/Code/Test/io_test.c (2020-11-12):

// This code simulates RPi GPIO communication with the display decoder,
// Chip: AVR, EEPROM: 128B, SRAM: 128B, flash: 2kB, THT ATTINY2313-20PU DIL20

#include <util/delay.h>
#include <avr/io.h>

// Base frequency of the built in clock 1MHz
#undef F_CPU
#define F_CPU 1000000UL

int main(void)
{
    // Set all pins of port B to outputs.
    DDRB = 0b11111111;
    
    // The output binary number will only be on first 4 pins (12, 13, 14, 15)
    // Initialize to no output.
    PORTB = 0b00000000;     // All outputs off.
    _delay_ms(5000);        // Wait for the decoder to boot and show boot animation for a while.
   
    // Send boot Ok signal, number 8.
    PORTB = 8;
    _delay_ms(2000);
 
    while(1)
    {
        // Send all displayable characters.
        for(int i = 0; i<16; i++) {
            PORTB = i;
            _delay_ms(700);
        }
        _delay_ms(200);
    }
}

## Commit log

2020-04-21 Adding kicad sources
    [schema.kicad_pcb, schema.sch]
2020-04-22 Add controller board schematics
    [archery.kicad_pcb, archery.sch, schema.kicad_pcb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]
2020-04-22 Switch driver IC
    [archery.sch]
2020-04-23 Solving ERC
    [controller.kicad_pcb, controller.sch, splitter.kicad_pcb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]
2020-05-02 Identify control pins
    [controller.sch, splitter.sch]
2020-05-03 Splitter schema
    [splitter.sch]
2020-05-29 finish splitter schema
    [splitter.sch]
2020-05-29 Add control LED
    [splitter.sch]
2020-05-31 Assign footprints
    [controller.sch]
2020-06-05 Assign parts
    [splitter.sch]
2020-10-26 swicth for avr
    [controller.sch, splitter.sch]
2020-11-10 Add information
    [controller.kicad_pcb, controller.sch, pin_config.txt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]
2020-11-12 Update schematics
    [controller.sch]
2020-11-16 update schemas
    [controller.sch, splitter.sch]
2020-11-17 update schematic
    [controller.sch]
2020-11-18 Add controller board
    [controller.sch]
2020-11-18 Finish PCBs
    [controller.kicad_pcb, controller.sch, splitter.sch]
2020-11-19 Reinforce output
    [controller.kicad_pcb, controller.sch, splitter.kicad_pcb]
2020-11-20 Add display breakout board
    [breakout.kicad_pcb, breakout.sch]
2020-11-21 Export -pcbs
    [breakout.kicad_pcb, controller.kicad_pcb, splitter.kicad_pcb]
2020-11-23 Update resistor values
    [controller.kicad_pcb, controller.sch]
2020-11-23 Fix relay symbol
    [splitter.kicad_pcb, splitter.sch]
2020-11-25 Update splitter board
    [splitter.kicad_pcb, splitter.sch]
2020-11-25 Make more precise plots
    [breakout.kicad_pcb, controller.kicad_pcb, splitter.kicad_pcb]
2020-11-25 Simplify relay control
    [splitter.kicad_pcb, splitter.sch]
2020-11-26 Add bypass caps and filtering
    [controller.kicad_pcb, controller.sch, splitter.kicad_pcb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]
2020-11-26 More separation
    [splitter.kicad_pcb]
2020-11-26 Old version, do not use
    [pin_config.txt]
2020-11-26 Add kicad part lists
    [controller.kicad_pcb, parts.csv]
2020-11-29 Add various exports
    [breakout.kicad_pcb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]
2021-01-15 Add dxf export
    [breakout-B_Cu.dxf, breakout-B_Mask.dxf, breakout-Eco2_User.dxf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]
2021-02-15 Add drill files
    [breakout-B_Cu.gbr, breakout-B_Mask.gbr, breakout-Eco2_User.gbr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]
2021-02-18 Update files
    [controller-B_Cu.dxf, controller-B_Mask.dxf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]
2021-03-03 update capacitors
    [controller-B_Cu.dxf, controller-B_Mask.dxf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]
2021-04-25 Update splitter
    [parts.csv, splitter-B_Cu.dxf, splitter-B_Mask.dxf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]
2021-04-25 Update controller
    [controller-B_Cu.dxf, controller-B_Mask.dxf, controller-Eco2_User.dxf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]
2021-06-06 add guide
    [burner.kicad_pcb, burner.sch]
2021-06-10 revision 2 boards
    [breakout-B_Cu.dxf, breakout-B_Mask.dxf, breakout-Eco2_User.dxf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]
2021-06-14 Remove version 1 board
    [breakout-B_Cu.dxf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]
2021-06-14 Redesign for sandwich pi
    [burner-B_Cu.dxf, burner-B_Mask.dxf, burner-Eco2_User.dxf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]
2021-06-14 Mark revisioin
    [breakout-B_Cu.dxf, breakout-B_Mask.dxf, breakout-Eco2_User.dxf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]
2021-06-15 make way for usb
    [splitter-B_Cu.dxf, splitter-B_Mask.dxf, splitter-Eco2_User.dxf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]
2021-06-26 mark pin 1
    [controller-B_Cu.dxf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]
2021-06-26 reinforce some copper
    [breakout-B_Cu.dxf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]
2021-06-26 move pin mark
    [breakout-B_Cu.dxf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]
